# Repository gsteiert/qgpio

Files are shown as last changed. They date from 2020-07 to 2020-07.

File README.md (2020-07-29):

# qgpio
Qwiic GPIO expander
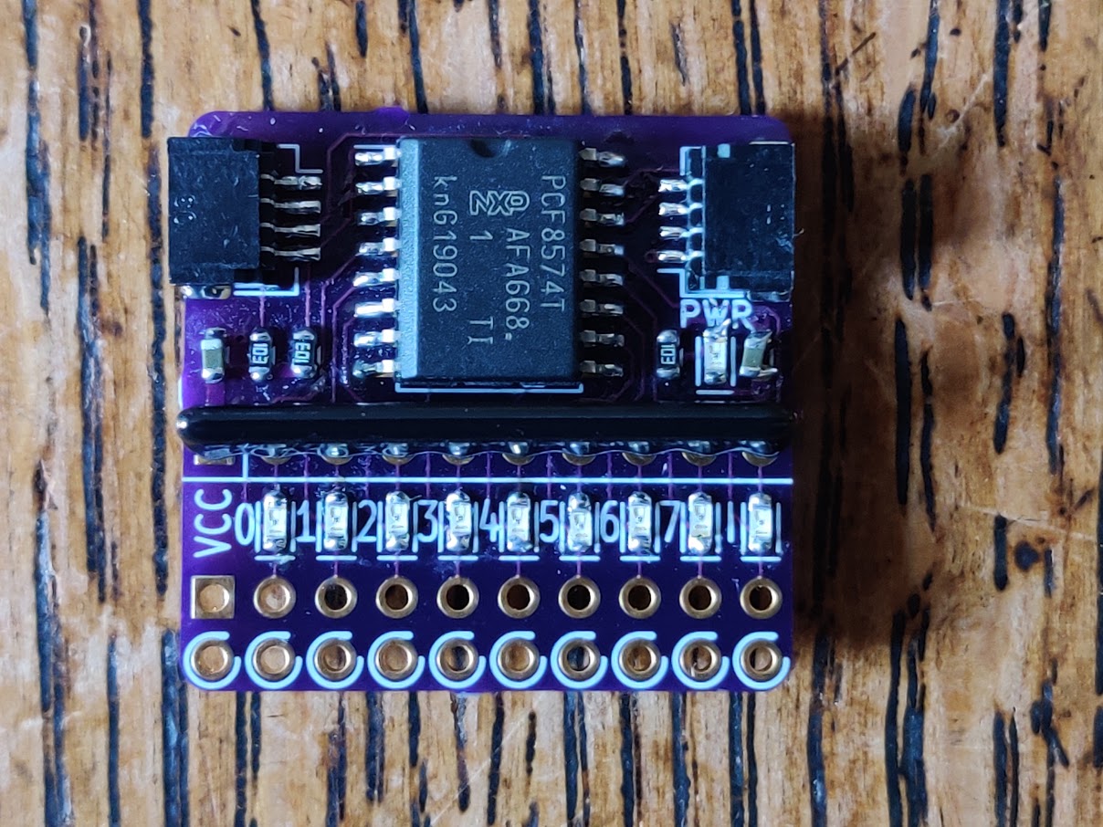
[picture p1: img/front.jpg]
front picture


This is a PCF8574 based GPIO expander with Qwiic connectors.
Each GPIO and the INT signal go to a header pin and have and LED that indicates when the signal is low.  The signals go to a dual row header with one row grounded so that any signal can be shorted with a jumper.  There is also an LED to indicate when the board is powered. 

This design is released under CC0 1.0 Universal license.

[Schematic print](qgpio.pdf)

[Follow this project on Hackaday](https://hackaday.io/project/173648-qgpio)

You can [order bare boards from OSH Park](https://oshpark.com/shared_projects/7lsaSVpY)

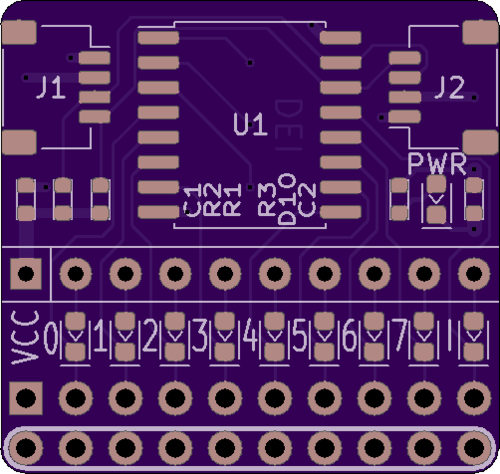
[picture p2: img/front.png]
front pcb

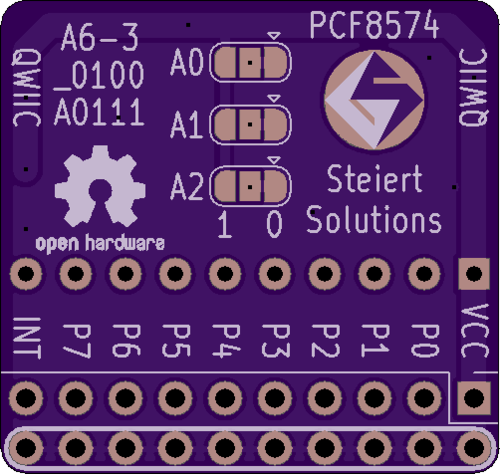
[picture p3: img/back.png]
back pcb

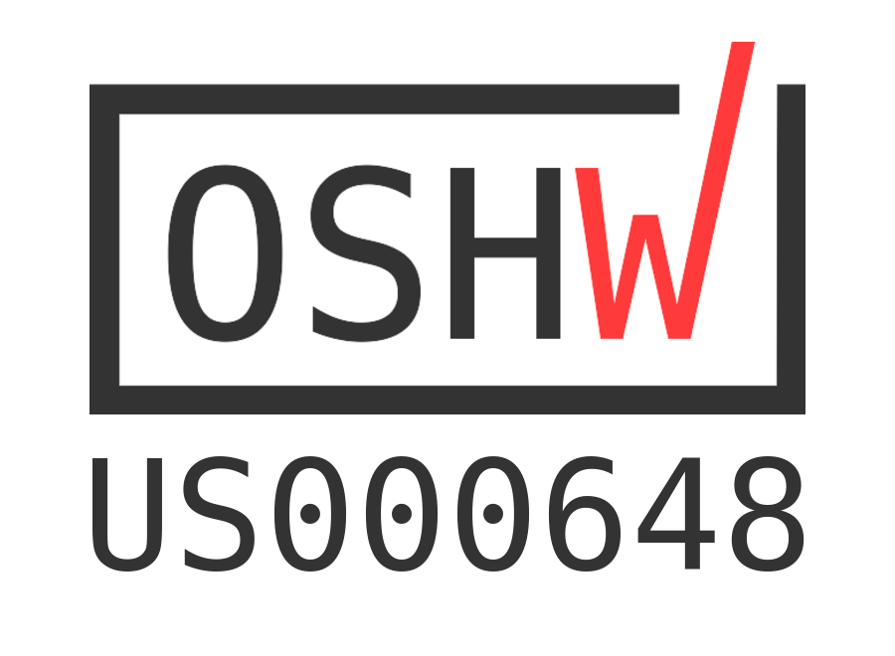
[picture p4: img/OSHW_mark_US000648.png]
OSHWA US000648 (https://certification.oshwa.org/us000648.html)


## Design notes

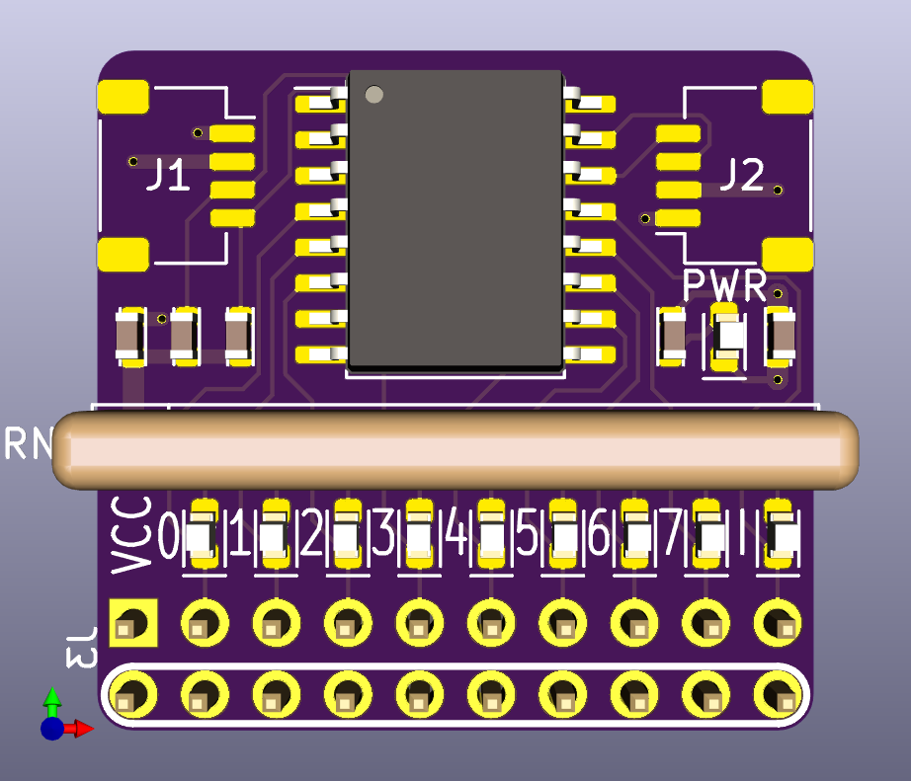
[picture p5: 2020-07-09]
img/qgpio_3d_f.png

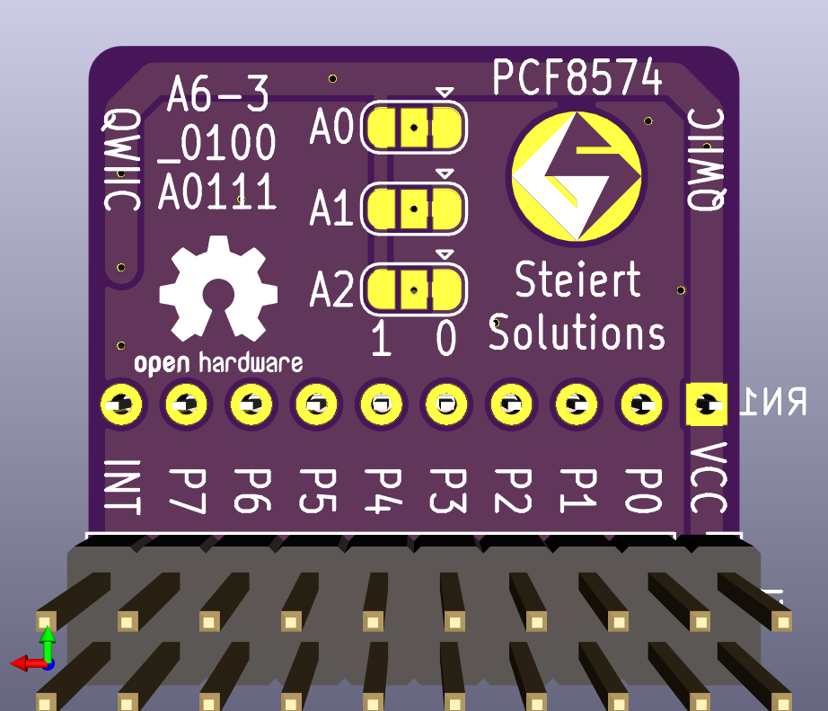
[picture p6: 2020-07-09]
img/qgpio_3d_b.png

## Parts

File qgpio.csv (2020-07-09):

Reference | Quantity | Value | Footprint | Datasheet | Digikey | MPN | Mouser
C1 C2 | 2 | 1uF | footprint:C0603 | https://ds.yuden.co.jp/TYCOMPAS/ut/detail?pn=EMK107BJ105KA-T%20%20&u=M | 587-1251-1-ND | EMK107BJ105KA-T | 963-EMK107BJ105KA-T
D1 D2 D3 D4 D5 D6 D7 D8 D9 D10 | 10 | LED | footprint:LED_0603_1608Metric | http://optoelectronics.liteon.com/upload/download/DS22-2000-074/LTST-C190KGKT.PDF | 160-1435-1-ND | LTST-C190KGKT | 859-LTST-C190KGKT
GS1 | 1 | GS_logo | footprint:gs_logo_200mil | http://dei.steiert.net/
J1 J2 | 2 | I2C_STANDARDQWIIC | Connector_JST:JST_SH_SM04B-SRSS-TB_1x04-1MP_P1.00mm_Horizontal | http://www.jst-mfg.com/product/pdf/eng/eSH.pdf?5ec58813d214e | PRT-14417-ND | PRT-14417 | 474-PRT-14417
J3 | 1 | Conn_02x10_Odd_Even | Connector_PinHeader_2.54mm:PinHeader_2x10_P2.54mm_Vertical | https://cdn.amphenol-icc.com/media/wysiwyg/files/drawing/77313.pdf | 77313-418-20LF-ND | 77313-418-20LF | 649-77313-418-20LF
JP1 JP2 JP3 | 3 | SolderJumper_3_Bridged12 | Jumper:SolderJumper-3_P1.3mm_Bridged12_RoundedPad1.0x1.5mm
LOGO1 | 1 | OSHW-LOGOS | Symbol:OSHW-Logo2_7.3x6mm_SilkScreen | https://www.oshwa.org/
R2 R1 R3 | 3 | 10K | footprint:C0603 | https://www.yageo.com/upload/media/product/productsearch/datasheet/rchip/PYu-RC_Group_51_RoHS_L_10.pdf | 311-10KGRCT-ND | RC0603JR-0710KL | 603-RC0603JR-0710KL
RN1 | 1 | R_Network09_US | Resistor_THT:R_Array_SIP10 | http://www.vishay.com/docs/31509/csc.pdf | CSC10KCC-ND | CSC10A0110K0GEK | 71-CSC10A0110K0GEK
U1 | 1 | PCF8574A | Package_SO:SOIC-16W_7.5x10.3mm_P1.27mm | http://www.nxp.com/documents/data_sheet/PCF8574_PCF8574A.pdf | 568-1074-1-ND | PCF8574ATD-T | 771-PCF8574ATD-T

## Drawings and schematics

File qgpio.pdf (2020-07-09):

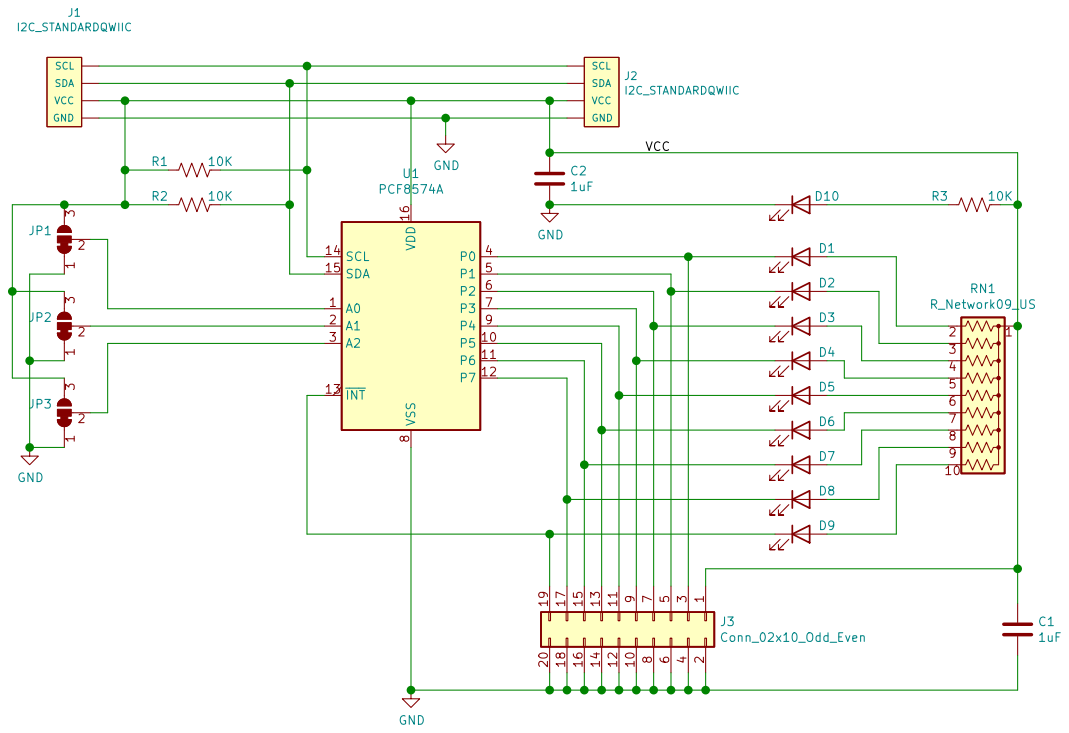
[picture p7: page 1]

File: qgpio.sch Sheet: / Steiert Solutions

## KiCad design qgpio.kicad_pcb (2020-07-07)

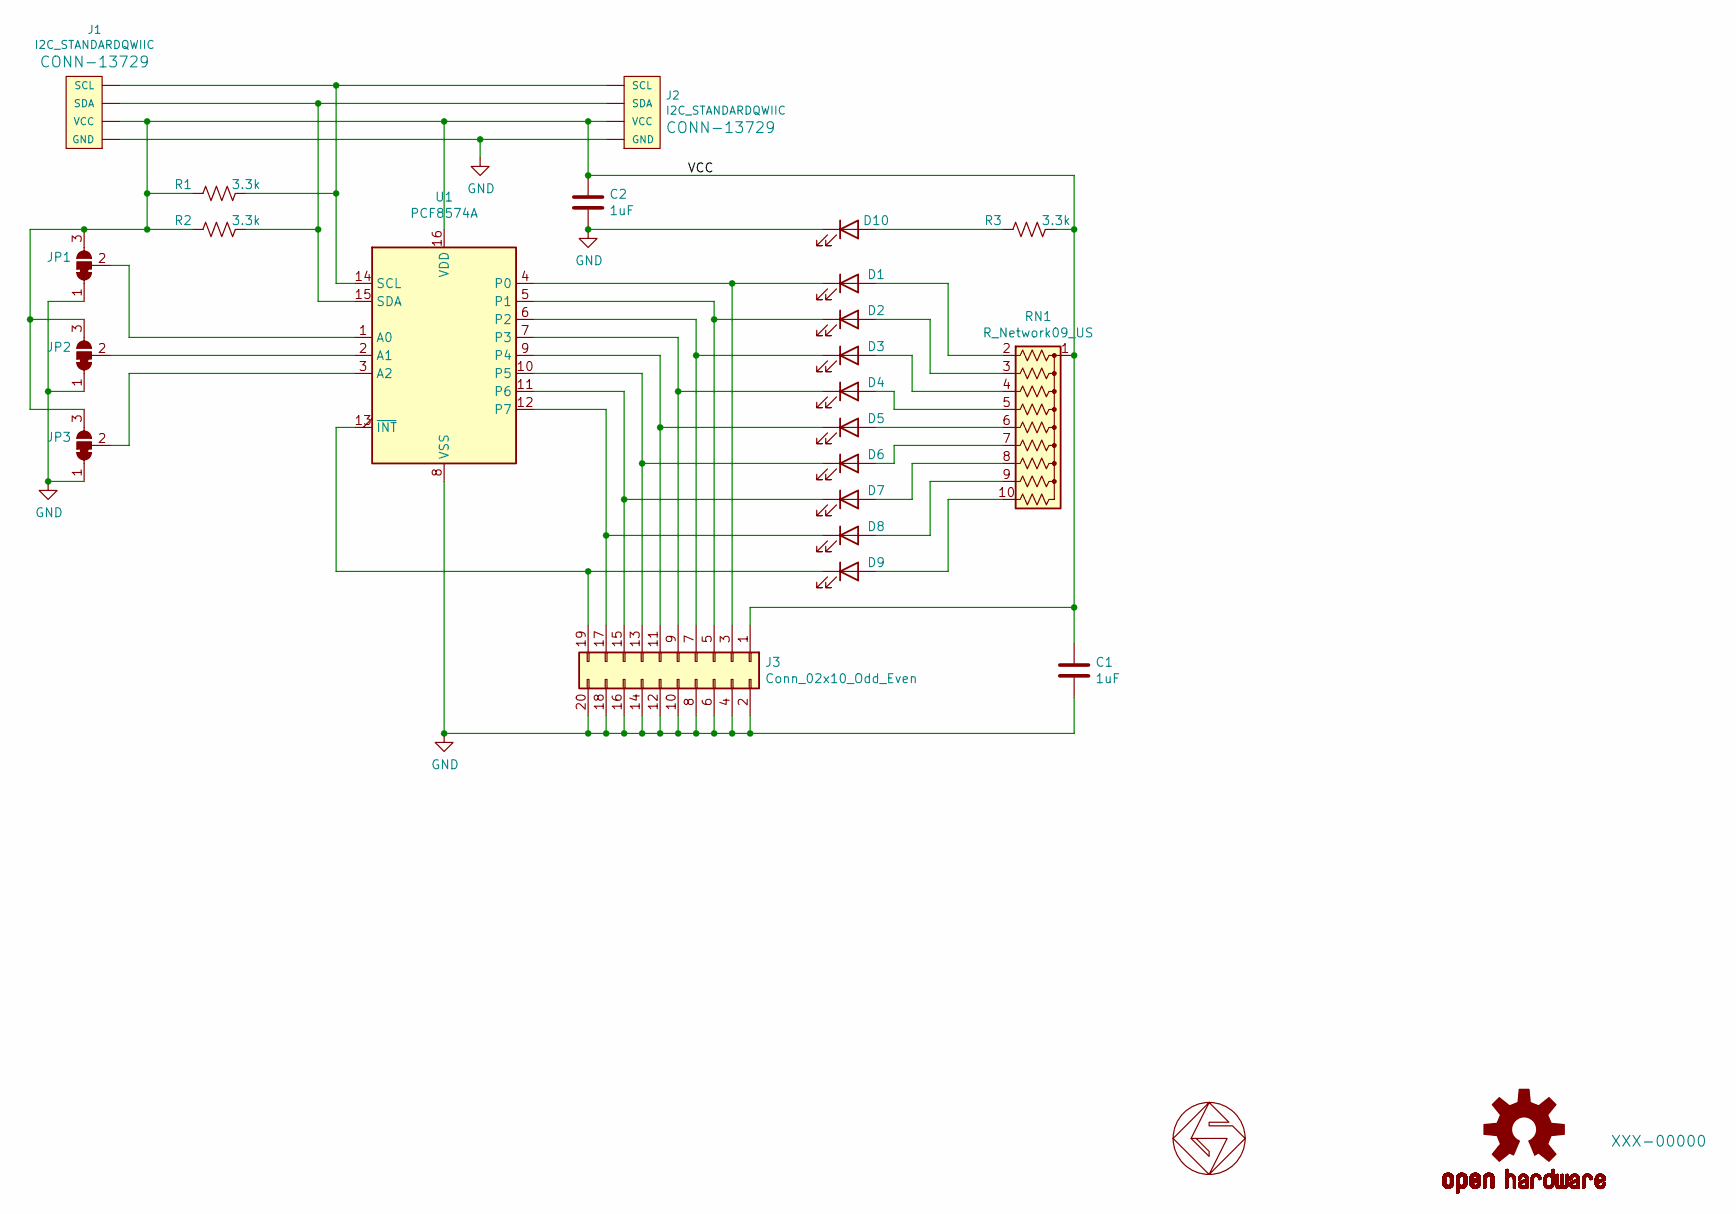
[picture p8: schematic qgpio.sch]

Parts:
C1, C2: 1uF; C0603
D1, D2, D3, D4, D5, D6, D7, D8, D9, D10: LED; LED_0603_1608Metric
GS1: GS_logo; gs_logo_200mil
J1, J2: I2C_STANDARDQWIIC; JST_SH_SM04B-SRSS-TB_1x04-1MP_P1.00mm_Horizontal
J3: Conn_02x10_Odd_Even; PinHeader_2x10_P2.54mm_Vertical
JP1, JP2, JP3: SolderJumper_3_Bridged12; SolderJumper-3_P1.3mm_Bridged12_RoundedPad1.0x1.5mm
LOGO1: OSHW-LOGOS; OSHW-Logo2_7.3x6mm_SilkScreen
R1, R2, R3: 3.3k; C0603
RN1: R_Network09_US; R_Array_SIP10
U1: PCF8574A; SOIC-16W_7.5x10.3mm_P1.27mm

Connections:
/VCC: C1.1, C2.1, J1.2 (VCC), J2.2 (VCC), J3.1, JP1.3 (B), JP2.3 (B), JP3.3 (B), R1.2, R2.2, R3.1, RN1.1 (common), U1.16 (VDD)
GND: C1.2, C2.2, D10.1 (K), J1.1 (GND), J2.1 (GND), J3.2, J3.4, J3.6, J3.8, J3.10, J3.12, J3.14, J3.16, J3.18, J3.20, JP1.1 (A), JP2.1 (A), JP3.1 (A), U1.8 (VSS)
unnamed: D1.1 (K), J3.3, U1.4 (P0)
unnamed: D1.2 (A), RN1.2 (R1)
unnamed: D2.1 (K), J3.5, U1.5 (P1)
unnamed: D2.2 (A), RN1.3 (R2)
unnamed: D3.1 (K), J3.7, U1.6 (P2)
unnamed: D3.2 (A), RN1.4 (R3)
unnamed: D4.1 (K), J3.9, U1.7 (P3)
unnamed: D4.2 (A), RN1.5 (R4)
unnamed: D5.1 (K), J3.11, U1.9 (P4)
unnamed: D5.2 (A), RN1.6 (R5)
unnamed: D6.1 (K), J3.13, U1.10 (P5)
unnamed: D6.2 (A), RN1.7 (R6)
unnamed: D7.1 (K), J3.15, U1.11 (P6)
unnamed: D7.2 (A), RN1.8 (R7)
unnamed: D8.1 (K), J3.17, U1.12 (P7)
unnamed: D8.2 (A), RN1.9 (R8)
unnamed: D9.1 (K), J3.19, U1.13 (~INT~)
unnamed: D9.2 (A), RN1.10 (R9)
unnamed: D10.2 (A), R3.2
unnamed: J1.3 (SDA), J2.3 (SDA), R2.1, U1.15 (SDA)
unnamed: J1.4 (SCL), J2.4 (SCL), R1.1, U1.14 (SCL)
unnamed: JP1.2 (C), U1.1 (A0)
unnamed: JP2.2 (C), U1.2 (A1)
unnamed: JP3.2 (C), U1.3 (A2)

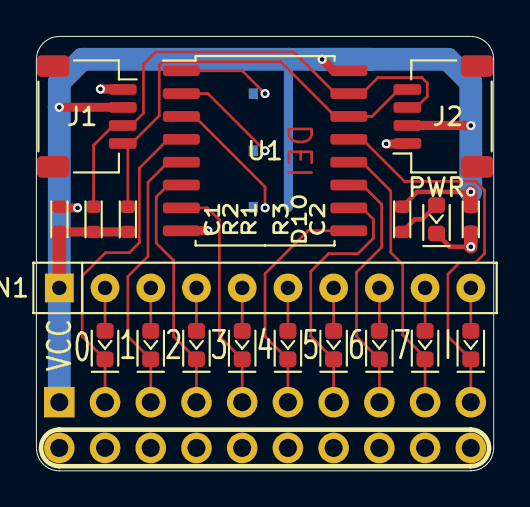
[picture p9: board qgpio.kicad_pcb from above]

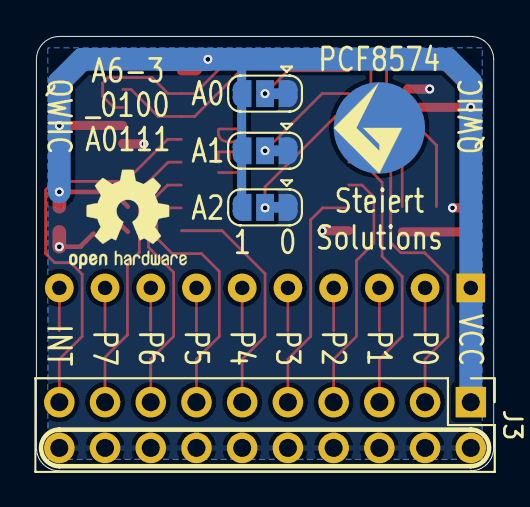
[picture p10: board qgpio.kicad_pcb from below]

Board: 2 copper layers, 25.4 x 24.1 mm, 25 parts (6 on the bottom side), 26 nets.

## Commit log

2020-06-27 changed ground silkscreen on dual row header
    [qgpio.kicad_pcb]
2020-07-07 added I2C addr to back silk
    [qgpio.kicad_pcb, qgpio.sch]
2020-07-09 cleaned up BOM
    [qgpio.csv, qgpio.sch]
2020-07-09 Update README.md
    updated flow
